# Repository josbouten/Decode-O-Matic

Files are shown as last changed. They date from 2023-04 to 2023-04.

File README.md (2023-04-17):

Decode-O-Matic is a diagnostic tool that you can use to check midi signals. Sometimes especially in elaborate midi setups a synth may not respond to a midi signal you are sending to it and you want to find out why that is the case. In actual practise being able to see whether any midi signal is sent to the device at all often solves most problems. Furthermore, being able to see the channel number of the midi signal the synth is receiving will often help to remedy the problem. Only in more difficult cases it may be necessary to have a look at the midi data itself.

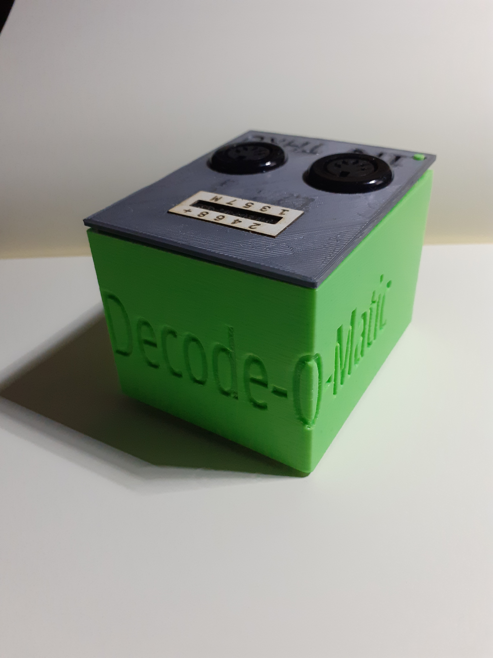
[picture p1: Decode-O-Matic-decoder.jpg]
Decode-O-Matic decoder


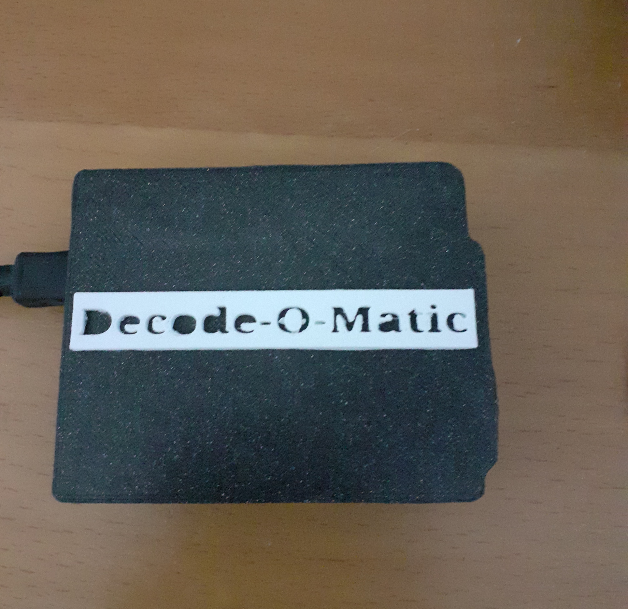
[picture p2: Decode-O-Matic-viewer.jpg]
Decode-O-Matic viewer


Decode-O-Matic consist of 2 parts. The decoder part is connected as a pass through between the synth and the midi interface. It is powered via USB. 

<foto van bovenkant van decode-o-matic>

It will show whether any midi data is received and it will show the data's channel. A second device is a midi viewer which can be connected via USB to a computer. 

Depending on the IDE you use, to compile the code you may need to install 2 libraries.

Dependencies for Decode-O-Matic-decoder when using platformio

	embeddedartistry/LibPrintf@^1.2.13
	khoih-prog/ESP8266TimerInterrupt@^1.6.0

Dependencies for Decode-O-Matic-viewer when using platformio

	embeddedartistry/LibPrintf@^1.2.13

Warning: Using D0 and D1 on the Wemos D1 R1 implies that you cannot upload code or use a serial terminal to look at any printed output as long as they are connected to the IO-devices. Only if you disconnect D0 you can upload code. If you disconnect D1 and do not redefine its pin setting only then will the serial output be visible in the serial out. Using the "#define DEBUG" So you could temporarily redefine Q9 to get rid of the problem.

The decoder and viewer are interconnected wirelessly via ESP_NOW and form a small private network. They do not require any WiFi router or similar to be around. Nor do they need internet access. The decoder however will need to know the mac address of the viewer. In de decoder code you need to fill the "broadcastAddress" with the proper address: 

uint8_t broadcastAddress[] = {0x00, 0x00, 0x00, 0x00, 0x00, 0x00};

You can find out what the MAC address of the viewer is by checking the log output of the arduino IDE when programming the device. Amongst its output it will give the MAC address. E.g.

	esptool.py v3.0
	Serial port /dev/ttyUSB0
	Connecting....
	Chip is ESP8266EX
	Features: WiFi
	Crystal is 26MHz
	MAC: xx:xx:xx:xx:xx:xx
	Uploading stub...
	Running stub...
	Stub running...
	Changing baud rate to 460800
	Changed.
	Configuring flash size...
	Auto-detected Flash size: 4MB
	Compressed 368320 bytes to 261438...
	Wrote 368320 bytes (261438 compressed) at 0x00000000 in 5.9 seconds (effective 500.4 kbit/s)...
	Hash of data verified.

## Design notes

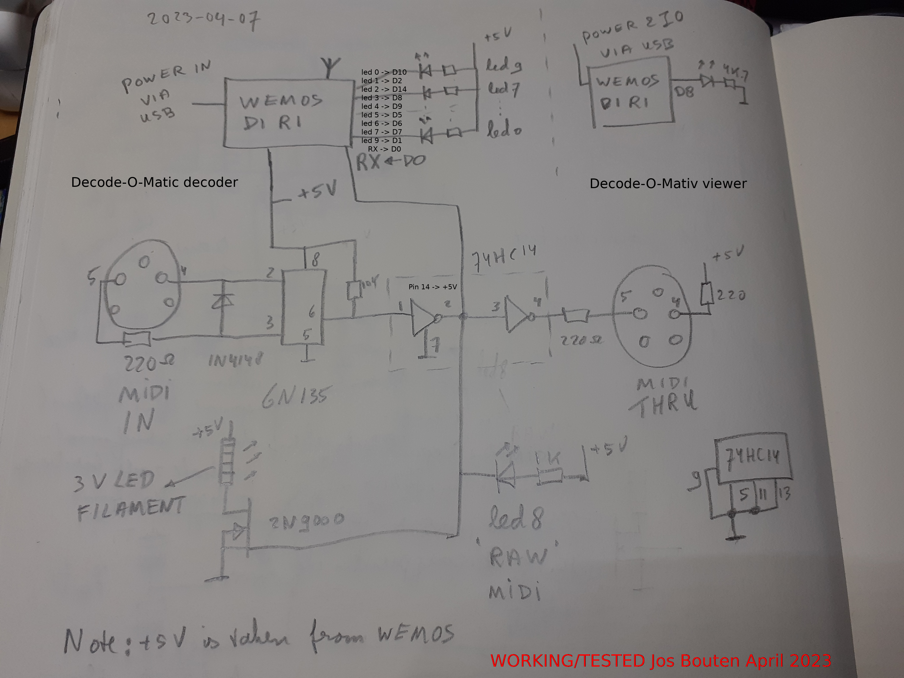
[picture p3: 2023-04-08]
Decode-O-Matic-_-schematic_April_2023.jpg

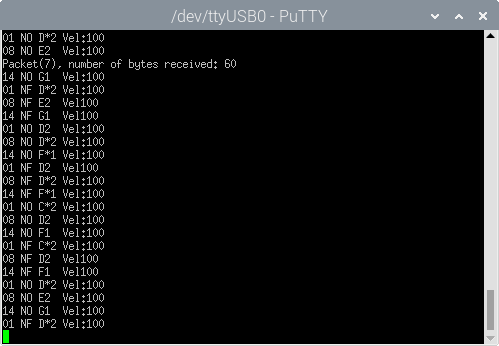
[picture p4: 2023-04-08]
Decode-O-Matic-viewer/pictures/putty_03.png

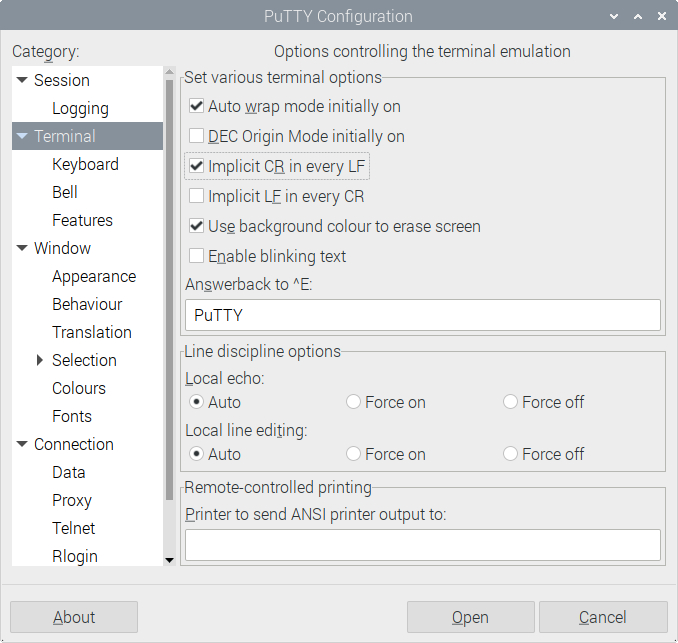
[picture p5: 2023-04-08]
Decode-O-Matic-viewer/pictures/putty_02.png

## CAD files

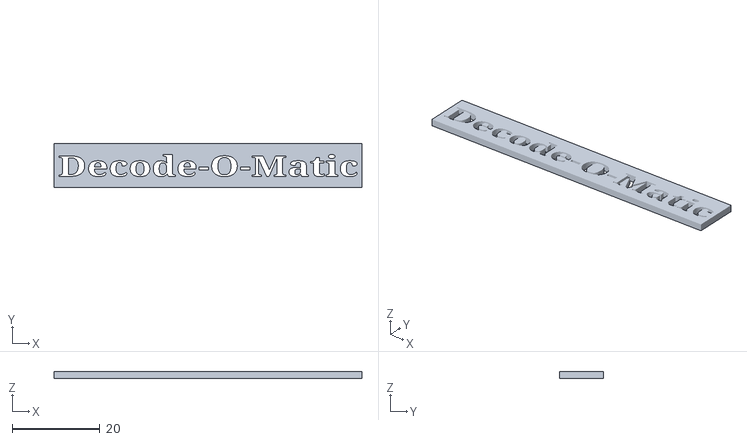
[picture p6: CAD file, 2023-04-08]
STL/Decode-O-Matic-viewer_-_text_2mm_01.stl
70.0 x 10.0 x 1.50

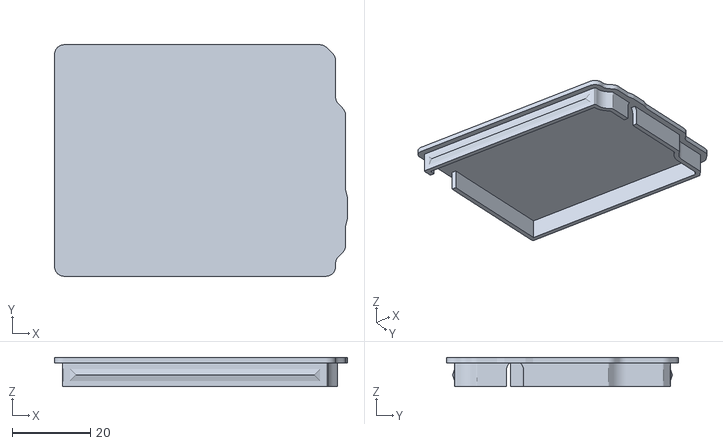
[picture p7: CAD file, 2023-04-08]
STL/Decode-O-Matic-viewer_top.stl
75.1 x 59.3 x 7.50

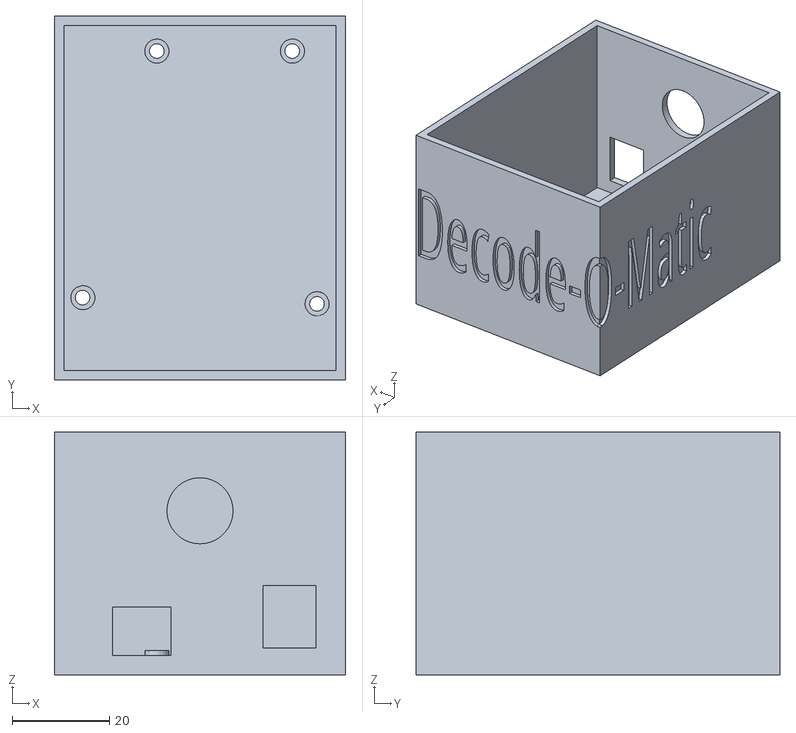
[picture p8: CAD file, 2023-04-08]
STL/Decode-O-Matic-decoder_-_bottom_v0.4.stl
60.0 x 75.0 x 50.0

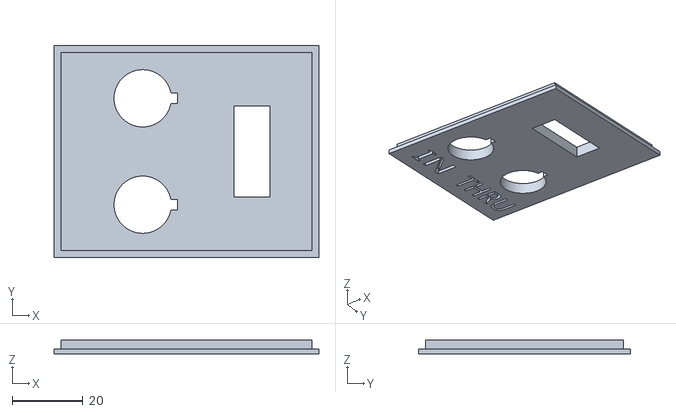
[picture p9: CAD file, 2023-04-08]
STL/Decode-O-Matic_decoder_-_top_v0.2.stl
75.0 x 60.0 x 4.00

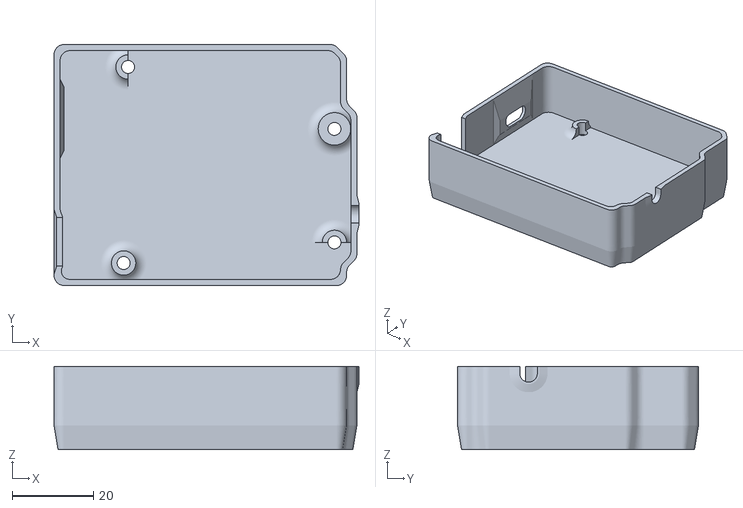
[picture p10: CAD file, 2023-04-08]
STL/Decode-O-Matic-viewer-body.stl
75.1 x 59.3 x 20.5

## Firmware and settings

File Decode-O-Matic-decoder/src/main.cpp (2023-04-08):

// Decode-O-Matic
//
// Decode-O-Matic v0.1 20 July 2019
// To compile this code choose board "WeMos D1 R1"

// Original code by:  Nick Gammon
// Date:    11th April 2012.

// Version 1.4: 2023-03-15 Jos Bouten
// This program uses 9 LEDs to show on which channel a midi message it received.
// Led 0 .. 7 show channel 1 ... 8. When data on higher channels is received the 9th 
// led will be lit. The leds are activated immediately but will be deactivated 
// after a delay so that even short messages can be traced.
// The program collects the messages in a buffer and as soon as that is (nearly) filled
// the data is transfered via ESP_NOW to another ESP device.
// This communication is non blocking, so the decoder works without a receiving ESP device.
// The MAC address of the receiving ESP device is used to address it.
// You will need to set that to the proper value would you want to use this code.
// No WiFi router etc. is necessary, the devices communicate with each other
// in a direct way using ESP_NOW.

// Note the debug flag must not be defined during operation otherwise 
// Q9 will not be properly defined. As a consequence the HIGHCHANNEL 
// led will always be lit.

//#define DEBUG

#include <MIDI.h>
#include <ESP8266WiFi.h>
#include <espnow.h>
#include <LibPrintf.h>

const char version[] = "Decode-O-Matic v1.4";

// REPLACE WITH RECEIVER MAC Address
uint8_t broadcastAddress[] = {0x00, 0x00, 0x00, 0x00, 0x00, 0x00};

//
// define LEDs
//

/*
FLTR <number used in IDE> // <integer value> i.e. <name of pin(s) on silkscreen of wemos pcb>
D9 //  1 i.e.  D3 on wemos D1 R1
D8 //  0 i.e. D10 on wemos D1 R1
D7 // 13 i.e.  D7 == D11 on wemos D1 R1
D6 // 12 i.e.  D6 == D12 on wemos D1 R1
D5 // 14 i.e.  D5 == D13 on wemos D1 R1 = blue SCK LED
D4 //  4 i.e.  D9 (dus niet D4!).
D3 //  5 i.e.  D8 (dus niet D3!).
D2 // 16 i.e. D14 (dus niet D2!).
D1 //  1 i.e. D15 (dus niet D1!).
D0 //  3 i.e.  D2 on wemos D1 R1
A0 // no responding pin found
*/

int Q0 = D10; // 15 i.e. 1st LED
int Q1 = D2;  // 16 i.e. 2nd LED
int Q2 = D14; //  4 i.e. 3rd LED
int Q3 = D8;  //  0 i.e. 4th LED
int Q4 = D9;  //  2 i.e. 5th LED
int Q5 = D5;  // 14 i.e. 6th LED
int Q6 = D6;  // 12 i.e. 7th LED
int Q7 = D7;  // 13 i.e. 8th LED
// The 9th LED is hard wired to the midi input.
#ifdef DEBUG
  int Q9 = D7; // replacement for debug purposes
#else
  int Q9 = D1;  //  4 i.e. 10th LED
#endif

/* ----------------------------------

Warning: Using D0 and D1 on the Wemos D1 R1 implies
that you cannot upload code or use a serial terminal
to look at any printed output as long as they are connected
to the IO-devices.
Only if you disconnect D0 you can upload code.
If you disconnect D1 and do not redefine its pin setting 
only then will the serial output be visible in the serial out.
Using the "#define DEBUG" So you could temporarily redefine Q9 to get rid of the problem.

   ---------------------------------- */

int BUTTON = Q9;
int HIGHCHANNEL = Q9;

int LED[9] = { Q0, Q1, Q7, Q6, Q5, Q4, Q3, Q2, Q9};

#define NR_COUNTERS 16
#define MAX_COUNT 40
volatile int delayCounter[NR_COUNTERS]; // Used to switch leds off after a delay.

// These defines must be placed at the beginning before #include "ESP8266TimerInterrupt.h"
// _TIMERINTERRUPT_LOGLEVEL_ from 0 to 4
// Don't define _TIMERINTERRUPT_LOGLEVEL_ > 0. Only for special ISR debugging only. Can hang the system.
#define TIMER_INTERRUPT_DEBUG         0
#define _TIMERINTERRUPT_LOGLEVEL_     1

// Select a Timer Clock
#define USING_TIM_DIV1                false           // for shortest and most accurate timer
#define USING_TIM_DIV16               false           // for medium time and medium accurate timer
#define USING_TIM_DIV256              true            // for longest timer but least accurate. Default

#include "ESP8266TimerInterrupt.h"

volatile uint32_t lastMillis = 0;
volatile uint8_t brightnessValue = 21;
volatile uint8_t delta = 1;

#define TIMER_INTERVAL_MS  1000

// Init ESP8266 timer 1
ESP8266Timer ITimer;

void IRAM_ATTR TimerHandler() {
  bool atLeastOne = false;
  for (byte i = 0; i < NR_COUNTERS; i++) {  
    if (i > 7) {
      if (delayCounter[i] > 0) {
        digitalWrite(LED[i % 8] , HIGH);
        digitalWrite(LED[8], HIGH); // high channel led
        atLeastOne = true;
      }
    } 
    else {
      digitalWrite(LED[i] , delayCounter[i] > 0 ? HIGH: LOW);
    }
    if (delayCounter[i] > 0) {
      delayCounter[i]--;
    }
  }
  if (!atLeastOne)
    digitalWrite(LED[8], LOW);      
}

//=======================================================================
// End timer stuff.

#define MAX_NR_BYTES 60 // MUST be <- 250!

// Structure example to send data
// Must match the receiver structure
typedef struct struct_message {
  byte size;
  char bytes[MAX_NR_BYTES];
} struct_message;

struct_message midiData;
int counter = 1;

const int noRunningStatus = -1;
int runningStatus;
byte lastCommand;


void ledSetup() {
  for (int i = 0; i < 9; i++) {
    pinMode(LED[i], OUTPUT);
    digitalWrite(LED[i], LOW);
  }
}

#define INCREMENT 5 // 'Time' added to delay timer each time a message for a given channel is received.

void channelLedOn(int channel) {
  if (delayCounter[channel] < MAX_COUNT) {
    delayCounter[channel] += INCREMENT; 
  }
}

void channelLedOff(int channel) {
  delayCounter[channel] = 0;
}

void channelTest() {
  for (int i = 0; i < NR_COUNTERS; i++) {
    channelLedOn(i);
  }
}

// Callback when data is sent
void OnDataSent(uint8_t *mac_addr, uint8_t sendStatus) {
  printf("Sent packet(%d). ", counter++);
  if (sendStatus == 0){
    printf("Delivery success\n");
  }
  else{
    printf("Delivery fail\n");
  }
}

void RealTimeMessage(const byte msg) {
  printf("A real time message was detected: %d\n", msg);
} // end of RealTimeMessage

#define CNT 10000 // ESP watch dog retrigger counter

int getNext () {
  int cnt = 0;
  
  if (runningStatus != noRunningStatus)
  {
    int c = runningStatus;
    // finished with look ahead.
    runningStatus = noRunningStatus;
    return c;
  }

  // The MIDI serial in input is connected to RX<-D0.
  while (true)
  {
    while (Serial.available () == 0) {
      if ((cnt % CNT) == 0) {
          wdt_disable();  // Reset watch dog of ESP
      }
      cnt += 1;
    }
    byte c = Serial.read();
    if (c >= 0xF8)  // RealTime messages.
      RealTimeMessage(c);
    else {
      return c;
    }
  }

} // end of getNext

// Dump a system exclusive message in hex.
void readPastSysex() {
  int count = 0;
  while (true)
  {
    while (Serial.available () == 0) {}
    byte c = Serial.read ();
    if (c >= 0x80) {
      runningStatus = c;
      return;
    }
    if (++count > 32) {
      count = 0;
    }
  } // End of reading until all system exclusive done.
}

void setup() {
  Serial.begin(31250);  
 
  // The MIDI serial in input is connected to RX<-D0.

  // Set device as a Wi-Fi Station
  WiFi.mode(WIFI_STA);

  // Init ESP-NOW
  if (esp_now_init() != 0) {
    printf("Error initializing ESP-NOW\n");
    return;
  }

  // Once ESPNow is successfully Init, we will register for Send CB to
  // get the status of Trasnmitted packet
  esp_now_set_self_role(ESP_NOW_ROLE_CONTROLLER);
  esp_now_register_send_cb(OnDataSent);
  
  // Register peer
  esp_now_add_peer(broadcastAddress, ESP_NOW_ROLE_SLAVE, 1, NULL, 0);

  #ifdef DEBUG
    printf("\n");
    printf("\n");
    printf("%s\n", version);
  #endif
  delay(2000);

  // Prepare LEDs.
  ledSetup();
  for (int i = 0; i < NR_COUNTERS; i++) {
    delayCounter[i] = 20 - i;
  }
  channelTest();
  runningStatus = noRunningStatus;
  // Interval in microsecs.
  if (ITimer.attachInterruptInterval(TIMER_INTERVAL_MS * 100, TimerHandler))
  {
    printf("Starting ITimer OK.\n");
  }
  else {
    printf("Can't set ITimer correctly. Select another freq. or interval.\n");
  }
}

const char *notes[] = { "C", "C*", "D", "D*", "E", "F", "F*", "G", "G*", "A", "A*", "B" };

void handleMidi()
{
  static String timestamp = "";
  byte note;
  byte velocity;
  byte pressure;
  byte param;
  byte message;
  byte programNumber;
  byte value;
  static byte index = 0; // index to buffer containing midi bytes.
  byte song;
  byte sindex;

  wdt_disable(); // Reset watch dog of ESP

  byte c = getNext();

  if (((c & 0x80) == 0) && (lastCommand & 0x80))
  {
    runningStatus = c;
    c = lastCommand;
  }

  // Channel is in low order bits.
  int channel = (c & 0x0F); // Channels are counted from 0 ... 15 by machines.
  //printf("channel %02x\n", channel);
  if (delayCounter[channel] < MAX_COUNT) {
    delayCounter[channel] += INCREMENT;
  }

  channel++; // Channels are counted from 1 ... 16 by humans.
  // Messages start with high-order bit set.
  if (c & 0x80)
  {
    midiData.bytes[index++] = c; // Add the first byte.
    lastCommand = c;
    switch ((c >> 4) & 0x07)
    {
      case 0:
        note = getNext();
        midiData.bytes[index++] = note;        
        velocity = getNext(); // Note off
        midiData.bytes[index++] = velocity;
        break;

      case 1:
        note = getNext();
        midiData.bytes[index++] = note;        
        velocity = getNext(); // Note on
        midiData.bytes[index++] = velocity;
        break;

      case 2:
        note = getNext();
        midiData.bytes[index++] = note;        
        pressure = getNext(); // Polyphonic Pressure
        midiData.bytes[index++] = pressure;
        break;

      case 3:
        message =  getNext() & 0x7F; // Control Change
        midiData.bytes[index++] = message;
        param = getNext();
        midiData.bytes[index++] = param;
        break;

      case 4:
        programNumber = getNext(); // Program Change
        midiData.bytes[index++] = programNumber;
        break;

      case 5:
        pressure = getNext();  // After touch pressure
        midiData.bytes[index++] = pressure;
        break;

      case 6:
        value = getNext() | getNext() << 7; // Pitch wheel
        midiData.bytes[index++] = value;
        break;

      case 7:  // system message
        {
          lastCommand = 0;           // these won't repeat I don't think
          switch (c & 0x0F)
          {
            case 0:
              value = getNext(); // System Exclusive, Vendor ID
              midiData.bytes[index++] = value;
              readPastSysex(); // Read past sysex
              break;

            case 1:
              value = getNext();  // Time code.
              midiData.bytes[index++] = value;              
              break;

            case 2:
              sindex = getNext() | getNext() << 7; // Song position index.
              midiData.bytes[index++] = sindex;
              break;

            case 3:
              song = getNext(); // Song Select
              midiData.bytes[index++] = song;
              break;

            case 4:
            case 5:
            case 6:
            case 7:
            case 8:
            case 9:
            case 10:
            case 11:
            case 12:
            case 13:
            case 14:
            case 15:
              break;
          }
        }  
        break;
    }
  }
  if (index > MAX_NR_BYTES - 2) {
    midiData.size = index;
    for (int i = index - 6; i < index; i++) {
      printf("%02x ", midiData.bytes[i]);
    }
    printf("\n");
    esp_now_send(broadcastAddress, (uint8_t *) &midiData, sizeof(struct_message));
    index = 0;
  }
}

void loop() {
  handleMidi();
}

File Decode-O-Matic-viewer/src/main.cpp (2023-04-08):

/* 
  This program received midi data and prints it in a 
  human readable for to serial out.
  Sysex data is skipped.
  You can cat the usb device it uses or use minicom or other software 
  to visualise the output. The baudrate must be set to 112500 
  and you need to switch on 'add carriage return . 
*/

#include <Arduino.h>
#include <ESP8266WiFi.h>
#include <espnow.h>

// Version 1.0

//#define DEBUG 1

#define MAX_NR_BYTES 60
#define CNT 10

#define BUILDIN_LED 2
#define EXTERNAL_LED D8

// Structure example to receive data
// Must match the sender structure
typedef struct struct_message {
    byte size;
    char bytes[MAX_NR_BYTES];
} struct_message;

// Create a struct_message called myData
struct_message midiData;
byte byteIndex = 0;
byte lastCommand;
int counter = 1;

byte getNext() {
  if (byteIndex < midiData.size) 
  {
    return(midiData.bytes[byteIndex++]);
  }
  return(0xFF);
}

const char *notes[] = { "C", "C*", "D", "D*", "E", "F", "F*", "G", "G*", "A", "A*", "B" };

void decodeAndPrint() {
  byte note;
  byte velocity;
  byte pressure;
  byte param;
  byte message;
  byte programNumber;
  byte value;
  byte song;
  byte pointer;
  char tmp[6];

  while(byteIndex < midiData.size) {
    // Read from a circular buffer.
    byte c = getNext();
    if (((c & 0x80) == 0) && (lastCommand & 0x80))
    {
      c = lastCommand;
    }

    // channel is in low order bits
    int channel = (c & 0x0F) + 1;
    // messages start with high-order bit set
    if (c & 0x80)
    {
      lastCommand = c;
      switch ((c >> 4) & 0x07)
      {
        case 0:
          note = getNext();
          velocity = getNext(); // Note off
          sprintf(tmp, "%s%02d", notes[note % 12], (int) (note / 12) - 1);
          if (strlen(tmp) < 4) 
            printf("%02d NF %s%d  %3d\n", channel, notes[note % 12], (int) (note / 12) - 1, velocity);
          else 
            printf("%02d NF %s%d %3d\n", channel, notes[note % 12], (int) (note / 12) - 1, velocity);
          break;

        case 1:
          note = getNext();
          velocity = getNext(); // Note on
          sprintf(tmp, "%s%02d", notes[note % 12], (int) (note / 12) - 1);
          if (strlen(tmp) < 4)           
            printf("%02d NO %s%d  %3d\n", channel, notes[note % 12], (int) (note / 12) - 1, velocity);
          else 
            printf("%02d NO %s%d %3d\n", channel, notes[note % 12], (int) (note / 12) - 1, velocity);          
          break;

        case 2:
          note = getNext();
          pressure = getNext(); // Polyphonic Pressure
          printf("%02d PP %d PR:%0d\n", channel, note, pressure);
          break;

        case 3:
          message =  getNext() & 0x7F; // Control Change
          param = getNext();
          printf("%02d CC %d (0x%02x) Value:%3d\n", channel, message, message, param);
          break;

        case 4:
          programNumber = getNext(); // Program Change
          printf("%02d PC PG:%3d (0x%02x)\n", channel, programNumber, programNumber);
          break;

        case 5:
          pressure = getNext();  // After touch pressure
          printf("%02d %s %s%03d\n", channel, "AT", "Val:", pressure);
          break;

        case 6:
          value = getNext() | getNext() << 7; // Pitch wheel
          printf("%02d %s%03d\n", channel, "PW Val:", value);
          break;

        case 7:  // system message
          {
            lastCommand = 0;           // these won't repeat I don't think
            switch (c & 0x0F)
            {
              case 0:
                value = getNext(); // System Exclusive, Vendor ID
                if (value == 0xF1) {
                  printf("Connection test\n");
                } else {
                  printf("%s%03d\n", "sx=", value);
                }
                break;

              case 1:
                value = getNext();  // Time code.
                printf("%s%03d\n", "tc,type=", value);
                break;

              case 2:
                pointer = getNext() | getNext() << 7; // Song position pointer.
                printf("%s%03d\n", "sp=", pointer);
                break;

              case 3:
                song = getNext(); // Song Select
                printf("%s%03d\n", "ss=", song);
                break;

              case 4:
                printf("Reserved-4\n");
                break;

              case 5:
                printf("Reserved-5\n");
                break;

              case 6:
                printf("Tune-request\n");
                break;

              case 7:
                printf("End_of_Exclusive\n");
                break;

              case 8:
                printf("Timing_clock\n");
                break;

              case 9:
                printf("Reserved-9\n");
                break;

              case 10:
                printf("Start\n");
                break;

              case 11:
                printf("Continue\n");
                break;

              case 12:
                printf("Stop\n");
                break;

              case 13:
                printf("Reserved-13\n");
                break;

              case 14:
                printf("Active-Sensing\n");
                break;

              case 15:
                printf("Reset\n");
                break;
            }  // end of switch on system message
          }  // end system message
          break;
      }  // end of switch
    }  // end of if
    // #ifdef DEBUG
      else {
        printf("0x%02x == d%d?\n", c, c);
      }
    // #endif
    if ((byteIndex % CNT) == 0) {
          wdt_reset();
      }
  }
}

// Callback function that will be executed when data is received.
void OnDataRecv(uint8_t * mac, uint8_t *incomingData, uint8_t len) {
  memcpy(&midiData, incomingData, sizeof(midiData));
  printf("Packet(%d), number of bytes received: %d\n", counter++, midiData.size);    
  #ifdef DEBUG
    for (unsigned int i = midiData.size - 6; i < midiData.size; i++) {
      printf("%02x ", incomingData[i+1]);
    }
    printf("\n");
  #endif
  byteIndex = 0;
  // Toggle the led to signal data reception.  
  digitalWrite(EXTERNAL_LED, !digitalRead(EXTERNAL_LED)); 
  digitalWrite(BUILDIN_LED, !digitalRead(BUILDIN_LED)); 
  decodeAndPrint();
}

void setup() {
  // Initialize Serial Monitor.
  Serial.begin(115200);
  
  // Set device as a Wi-Fi Station.
  WiFi.mode(WIFI_STA);

  // Init ESP-NOW
  if (esp_now_init() != 0) {
    printf("Error initializing ESP-NOW\n");
    return;
  }
  printf("Ready to receive data.\n");
  
  // Once ESPNow is successfully initialized, we will register for recv CB to
  // get recv packer info.
  esp_now_set_self_role(ESP_NOW_ROLE_SLAVE);
  esp_now_register_recv_cb(OnDataRecv);

  pinMode(BUILDIN_LED, OUTPUT);
  pinMode(EXTERNAL_LED, OUTPUT);
  digitalWrite(BUILDIN_LED, LOW);
  digitalWrite(EXTERNAL_LED, LOW);
}

void loop() {

}
